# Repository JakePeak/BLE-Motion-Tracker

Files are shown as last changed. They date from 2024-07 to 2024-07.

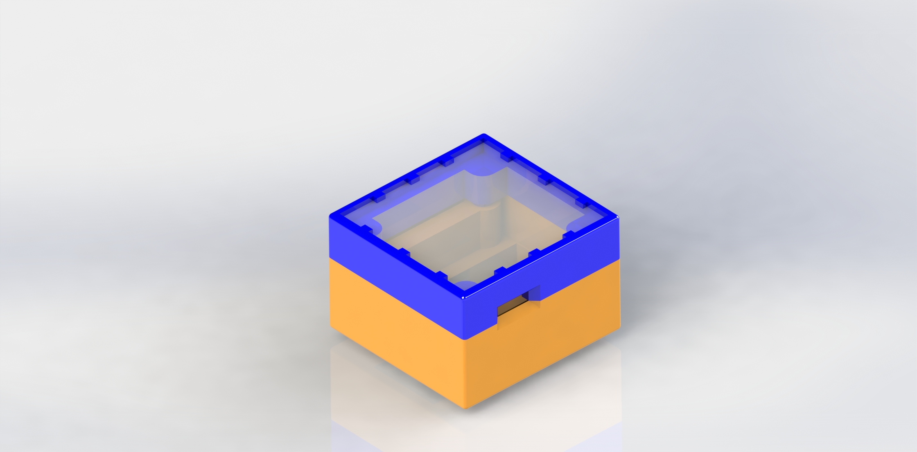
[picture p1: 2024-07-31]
PCB/Mounting/Rendered.JPG

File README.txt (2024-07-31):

BLE Motion Tracker
==========================================

This is a 200+ hour personal project with the purpose of plotting a live
graph of the current location of the motion tracker.  This was accomplished
through Bluetooth LE communications, Inertial Measurement Unit position
approximations, and python's matplotlib plotting capabilities.

This is truly a full-stack project; it scales all levels of design from custom
PCB design and manufacturing to developing a full user interface.  Almost all
code was written in C/C++, with a little python.  At the heart of this
project's functionality lies the BlueNRG M2SA module, which was used to
opperate the PCB and run all bluetooth communications with the host computer.

Throughout this project, I have picked up many skills.  These are all 
documented with their respect parts of the project, located throughout this 
repository.  As well, some of the most time-consuming bugs and errors I 
encountered are documented for any who stumble upon this project when searching
for solutions to these bugs like I have.

For more information on each individual sub-component of this project, look
for the respective README files in that location of the repository.

If you have any questions, I would love to answer them.  Attached is my 
LinkedIn profile, so you can get in touch.
www.linkedin.com/in/jake-ashpole-3b73542a7

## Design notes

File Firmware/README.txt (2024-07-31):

On-Chip Firmware
=======================================

One of the main reasons behind this project was an opportunity to teach myself
embedded software/firmware and flashing.  Thoughout this project, I will refer
to any embedded software as firmware, as firmware is a loosely defined concept.
In this directory, there are 4 folders.  Debug_LED contains a WISE Studio
project that was used to unit test and debug on-board functions and peripherals.
The rest were used as modifications to the BLE_SensorDemo demo project provided
by the WISE Studio software development kit.  This README will contain 5
sections: design overview, running the project in the IDE, skills involved, 
bugs, and references.

Design Overview
---------------------------------------

The initial concept behind the design is a 3-state state machine.  After an
on-boot initialization process, the device would enter a "connect" state, 
where it would try and develop a connection.  Once a connection is found, it
enters a "pause" state.  From the pause state, the user can activate the device,
moving into the "active" state where all peripherals are running and data is 
being send over bluetooth low energy to the external application.  The user
can toggle between pause and active states, and should the user disconnect the
device will reenter the "connect" state.

On a peripheral level, the microcontroller interacts with an LED using GPIO,
and a accelerometer using SPI.  Data is collected every select interval using
a timer through individually reading each data register.  As well, the 
microcontroller contains a build-in ADC bridge to measure the input voltage,
which is used alongside a model of output voltage decay in AAA Alkaline 
batteries to determine the battery percentage.

This device contains 6 GATT Services.  The first two are GATT and GAP services
for establishing connection.  The next 3 are the battery service, HID service, 
and device information service.  The battery service was used to hold the
battery level characteristic.  However, the HID service and device information
services are both skeleton services with little functionality, as windows has
poor support for BLE devices, which will be discussed in greater detail in the
bugs section.  The final service is a custom IMU service.  It contains 3 
characteristics: a boolean, used to change between active and pause states;
Sensor location and Speed, used to hold IMU data; a custom notify, which sends
a notification for the application to initiate a long read on the IMU data.

Running the Project
----------------------------------------

Inside BLE_SensorDemo/Release there are binary and hex files that can be
flashed without opening the project, should one desire.  Beyond this, running
the IDE will take some work.  First, download WISE Studio and its SDK off of
ST's website.  Then, opening the CPROJECT with wise studio contained within
this repository might work.  If it doesn't, then one must link the 
Additional_Source_Files to the project, specifically by right-clicking and
following the menu on the folder containing the main() function.  Doing this
project-wide breaks the SensorDemo_Config.h file, and with it all GATT 
functionality.  Afterwareds, copy the text of all the Aletered_Source_Files
into their respective files.  sensor.c contains all BlueNRG event callbacks.
SensroDemo_config.h contains the BLE stack memory allocation, which is very
buggy and the reason why I migrated my files from my own project to a demo
project.  SensorDemo_main.c contains the main function.  This should resolve
all errors, and allow for the code to be modified in the native IDE.

Debug_LED should just work, as it isn't a demo project since it has no 
bluetooth functionality.

Skills
----------------------------------------

- Embedded Firmware Design
	The core of this project was learning how to design firmware for
	microcontrollers.  I learned about numerous peripherals, register
	access, compiling, config, and flashing.  WISE studio is much more
	hands-on than the classic STM32CubeIDE, and on multiple dead end
	paths I ended up using it as well, so can confidently say that I
	am experienced in both IDEs, and with a greater understanding than most
	who simply use STM32CubeIDE for ST's products.

- Bluetooth Low-Energy Stack
	Bluetooth LE is a complex topic involving many standards and rules
	to follow.  Regardless of the microcontroller chosen, I am confident
	in my ability to design for BLE and execute.

- Flashing
	In this project, I used the built in UART flasher simply becuase it
	was cheaper than investing in a JTAG or other standard flasher.  
	However, after learning one method I am confident in my ability to 
	learn another, and have added microcontroller flashing to my skillset

- C Programming
	Wihle I already consider myself a skilled C programmer, practice makes
	perfect and writing/debugging a couple thousand lines of code on the 
	chip alone once again stands as a testament to my abilities.

- HID protocol
	Building the skeleton HID strucutre required me to learn the 
	foundations of HID, allowing me to make other devices HID-compliant

Bugs
----------------------------------------

1) WISE studio's BlueNRG_Stack_Initialization();
	The majority of this project was designed in a custom project rather
	than a demo project.  This was a much cleaner solution, but it ran
	into an issue.  The BlueNRG_Stack_Initialization function would always
	return an error.  I was unable to trace the root of this error beyond
	the User_config.h file, and like every other person I could find online,
	resorted to modifying a built-in demo application.  There is something
	innately wrong with WISE studio's custom projects, and I would like
	to document this as a warning for others using BlueNRG modules.

2) HOGP profile
	I have already discussed this under the windows_application readme,
	but there is more to it.  I was unable to translate all parts of this
	project into a HID device, as windows BLE doesn't perform a long read
	of the HID Report map.  As I couldn't alter the MTU due to limitations,
	my only option was a skeleton HOGP.  I believe this to be a bad 
	implementation, but I could see no way around it other than custom
	driver development

3) Burning IMU QFN package
	This project involved an accelerometer with a small footprint and a
	QFN package, which caused many setbacks.  As a hobbyist, my only option
	was to solder paste and heat gun.  This resulted in me burning 3/4 of
	my IMUs, to various degrees.  I would recommend avoiding QFN packages
	when possible, and if not like my situation, find and use a soldering
	specific heat gun with controllable temperatures.  Be it disfunctional
	SPI, broken pads, or busted MEMs devices damaged chips provided a host
	of issues.  While estimating position from IMU readins is already a 
	rather flawed system, damaged IMUs made my final project much less
	impressive, as the live location graphing was usually inaccurate.

4) Accelerometer SPI FIFO
	While polling individual registers works, it is much more elegant to
	read all registers at once through the accelerometer-provided FIFO.
	However, after a long time debugging this approach was abandoned.
	My accelerometer didn't like gaps between SPI data frames, and 
	my microcontroller supported a max data frame size of 32 bits, so
	I was sadly unable to get a reading out of the FIFO.  I left the
	FIFO config instructions in the final project, despite being unable
	to utilize them.

References
----------------------------------------

The microcontroller used, the BlueNRG-M2SA module, was very convenient in that
it could be hand-soldered.  While it had many bluetooth issues and limitations,
I would recommend it for hobbyists simply for the manufacturability.  From this
link, one can find the RF flasher utility, WISE studio, and the SDK.
https://www.st.com/en/wireless-connectivity/bluenrg-m2.html#documentation

The accelerometer has a host of useful functions, called APEX motion functions.
As well, the non-burnt gyroscope axis managed to be accurate to around 1/1000 
of a radian per second, so I do believe it to be a very powerful device.  Just
be cautious with temperature.
https://product.tdk.com/system/files/dam/doc/product/sensor/mortion-inertial/imu/data_sheet/ds-000451-icm-42670-p.pdf

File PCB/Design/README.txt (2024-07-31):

PCB Design
=================================

This folder contains the two iterations of my PCB design.  The first was never
ordered, but played a crucial role in the design process.  When designing, I
chose to use Altium, as I have used it though Illini Electric Motorsports.

Verson 1
---------------------------------

The first version of the PCB was much smaller.  It assumed components would
be mounted externally, and would be wired and soldered into vias.  As well,
I designed it before I knew the feasibility of soldering QFN packages for the
accelerometer, so left vias to manually wire into the accelerometer.  I decided
this was a poor solution, hence the redesign.  As well, the PCB manufacturer
I used had limited support for small boards, and my board was too small.  This
led me to redesign the board and make it larger, leaving space for more 
mounting holes.

Version 2
---------------------------------

The final version of the PCB.  It features additional mounting holes to 
directly mount the battery pack to the PCB, which while not a very resilient
solution was very convenient for keeping all electronic components together
during software/firmware development.  The PCB features a flashing switch, as
well as an on/off switch.  It has a USB-UART connector for utilizing the
microcontrollers UART bootloader.  It also uses an LED/resistor output, to
help debug and calculated to have low power consumption.  As well, SPI lines
are routed from the PCB to the accelerometer.  All other resistors are pull-up
resistors, and all capacitors are bypass capacitors.  J2 was originally a
connector, however it's footprint was wrong so wires were directly soldered to
the VIAs.  The board also utilizes two power planes (ground and 3V), making
it a 4 layer board.

Skills
---------------------------------

- Digital Circuit Design
	While simple, this project gave me an introduction to digital circuit
	design.  All my digital traces worked perfectly as intended.

- PCB design
	Outside of mounting holes, this is a relatively robust PCB.  I am more
	than capable of making it significantly smaller, but took advantage
	of the extra space requirements to improve manufacturability.

- Analog Circuit Design
	This feature did feature one analog component, the LED.  While simple,
	it was consistent and error-free

- Soldering
	Not only did I get to use classic soldering using an iron, I also got
	exposure to heat gun soldering and solder paste.  While I lost many
	accelerometers to this process, I am confident in my ability to 
	manufacture QFN packages in the future with use of reflow diagrams.
	I am a longtime solderer, and this was just another opportunity to
	work with it.

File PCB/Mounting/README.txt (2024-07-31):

PCB Mounting
===================================

This file contains the SolidWorks CAD documents used to produce the casing
for the PCB.  This was a rather simple construction, with attention to detail
to reduce the need for supports for 3d prints and make resource-efficient 
joining methods between different parts.  As well, a laser cutter was
used to cut out a plexiglass cap for the mount to leave the circuit on
display, since it was the heart of the project.  A final render is included
in this folder, as well as documents for laser cutting.

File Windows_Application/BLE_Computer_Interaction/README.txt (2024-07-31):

Overview of the Windows Application
=========================================

This directory contains the visual studio 2022 project in which the laptop
application which interacts with the motion tracker resides.  This document
consists of 5 segments: how to run the project in visual studio, how to
use the project, skills involved, largest bugs, and references.

How to Run in Visual Studio
-----------------------------------------
While the project should work fine on its own, any attempt to compile will
inevitably fail.  This project is dependent on two external libraries, the
C-python API and Eigen.  When I constructed this, I manually installed them
into the Visual Studio default library location, which would let me use them
on further projects.  If you would rather not, I recommend downloading both
libraries and altering the framework.h header file with the necessary paths
and .dlls.  Since this isn't designed to be a public utility, but rather a
skills showcase, hard-coding my personal setup made the most sense rather
than reuploading those APIs to Github.

Using the Project
-----------------------------------------
To start this project, double click or run the compiled executable from the
command line.  It should prompt you to select your python application.  While
I originally empedded python into the project, the embedded distribution 
has compatibility issues with importing libraries using the C-Python APIs, so
rather than embedded a full python download I opted to use the user's python.

After this, the application window should open.  It is rather simple, as 
this project focuses on the lower levels of the full-stack implementation.
The menu is rather reduntant, however the python tab is useful for configuring
the embedded python.  As for the buttons:
- Connect     --> connects the application to the device
- Pause       --> Pause the devices data collection (enters pause state)
- Unpause     --> Starts data collection (enters active state)
- Battery     --> Outputs current battery percentage
- Import File --> Select an external file to graph, ie. prior saved data
- Set Output  --> Allows for changing from the default output CSV
- Disconnect  --> Disconnects the application from the device

If the device has already been connected to the PC by finding it under the
extended connectable bluetooth devices list, then connect should complete
without error.  Then simply select unpause to start graphing.  The device
first will calibrate, which is signaled by the LED turning on until
calibration is complete.  Then data will be plotted live, until the window
is exited or the pause button is selected.

Skills Involved
-----------------------------------------
In creating this application, I primarily learned about different API sets,
as well as the windows system.

1) C++ coding with Object Oriented Programming (OOP)
	The way python interaction and bluetooth device interaction was coded
	closely followed the principles of OOP, and helped developed my
	programming skills.

2) win32 API set
	I used a large swath of the win32 api.  The most notable were the 
	BLE device node APIs, the device enumeration APIs, and the windowing
	APIs.  To help understand these and get my device to connect to them,
	I also researched the win32 device driver stack, although due to time
	constraints and the steep learning curve I left it for a later projet.
	Out of these API sets, the device enumeration APIs are the most
	generally useful, as I see myself working with other forms of device
	I/O in the future.

3) C-Python APIs
	After using these APIs, I strongly discourage their use.  They 
	natively introduced a host of bugs and compatibility issues, 
	especially with library imports.  However, I do find it very 
	appealing to be able to call python code from C, and could see myself
	utilizing them in the future, now that I know many of the issues to
	avoid when using them.

4) Eigen
	I used a little bit of Eigen and linear algebra to estimate position
	using the Inertial Measurement Unit.  The mathematics was interesting,
	and I found Eigen to be a very consistent solution to my problems.

5) Multithreading
	While I have already covered multithreading in advanced coursework,
	I opted to somewhat utilize it in this project.  The two locations
	where I used it was operating an independent 'python' thread and
	using asynchronous file IO to streamline data throughput over BLE.

6) Full-Stack Development
	The massive scope of this project as a whole provided an introduction
	to full-stack development unlike one any normal project could deliver.

Bugs
-----------------------------------------
As I have covered the numerous python bugs in that respective README, I will
not review them here.

- LEEnumerator driver
	The windows-provided basic BLE driver has numerous pitfalls, and almost
	pushed me to design my own.  If it doesn't detect a GATT profile
	device, then it will disconnect the device and won't permit 
	connections.  While not an elegent solution, I found the only way shy
	of designing my own driver was to build a mock HID Over Gatt Profile
	(HOGP) profile on my device.  While I followed all regulations and
	standards, I very much dislike the need for this solution simply 
	because the LEEnumerator driver doesn't need to have this arbitrary
	requirement, custom services work just fine if it detects any GATT
	profile.

- Dots Per Inch (DPI) nonfunctional with MatPlotLib
	When attempting to use the visual studio example code as the foundation
	of my windowing, I ran into an issue where after making MatPlotLib 
	calls my window would randomly resize.  I was able to track this issue
	down to an application error where it didn't inately use the system's
	DPI.  I suspect this issue could happen for many other reasons, and
	the solution was to add:
	SetThreadDpiAwarenessContext(DPI_AWARENESS_CONTEXT_SYSTEM_AWARE)
	as the application initialized.

- Bluetoothleapis.h poor documentation
	While not a bug, the documentation deserves it's own discussion.  As
	the only non-UWP microsoft API set to interact with BLE devices, it
	should have better documentation.  Notably, the documentation often
	confuses device handles with service handles.  If running into bugs
	with this API set, check which seems more intuitive first, as the 
	documentation sometimes directly contradicts itself as to which is 
	correct.

As with any project, bugs are commonplace, however these were some of the most
prominent bugs encountered.  That being said, I found Visual Studio 2022 to be
a very bug-free IDE which helped me solve my problems quickly and efficiently.

References
-----------------------------------------

The win32 documentation is very extensive, and for the most part, very good.
Below is the link to their error documentation, as sometimes the application
reports win32's error codes.
https://learn.microsoft.com/en-us/windows/win32/debug/system-error-codes--0-499-

To help learn how use the windowing APIs, I found "The PentaMollis Project"'s 
youtube series to be a lifesaver to quickly introduce the important features
of this vast API set.
https://www.youtube.com/playlist?list=PLWzp0Bbyy_3i750dsUj7yq4JrPOIUR_NK

The C-Python API reference manual, while not as thorough as it could be, was
essential for debugging, and is linked below.
https://docs.python.org/3/c-api/index.html

Bluetooth SIG does a great job documenting all of the defined profiles, and
allowed me to implement my ghost HOGP profile to get around LEEnumerator's 
defficiencies.
https://www.bluetooth.com/specifications/specs/

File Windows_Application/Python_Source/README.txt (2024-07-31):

Python Embedding Information
============================

Getting it Operational
----------------------------

In the windows application, I chose to embbed python using the c-python api,
which ultimately had many issues.  While most of this will work out of the
box, there are a couple steps that must be done.

1) Edit the path to <Python.h> to your own respective python.h
	- Make sure to have Numpy and Pandas installed

2) Edit the path to <Eigen\Dense> to your own eigen install
	- This is a rather easy library to download, so I didn't include
	  it in the final project

Notable Pitfalls and Bugs
----------------------------

Throughout the development of this project, the python embedded installation
took much longer than was anticipated due to a combination of external modules
and a nontrivial API.  Should anyone attempt to build their own embedded python
installation using this API, here are some recommentations.

1) External Modules (Numpy, MatplotLib) aren't designed to work well with this
API set.  These two modules gave me countless troubles, and here were my
solutions.
	- Numpy can only be initialized once
		- If you want to embed Numpy, Don't repeatedly Py_FinalizeEx()
		  and Py_Initialize().  As part of its startup, it only works
		  the first time.

	- Matplotlib rescales the application's DPI and steals focus
		- At least with win32, calling on Matplotlib is very dangerous.
		  SetThreadDpiAwarenessContext(DPI_AWARENESS_CONTEXT_SYSTEM_AWARE);
		  is was required, as it would rescale windows if they didn't
		  adapt to the system DPI that matplotlib would overlap
		- As well, if building your own animation method, use rcParams.
		  Specifically, "figure.raise_window" = False.  Without this,
		  every time the plot resets it steals focus, stoping the
		  user from accessing the rest of the application.

2) In my experience, I was unable to get the embedded windows distribution of
Python to work.  I believe this is because the API doesn't look for standard
modules in .pyc files, so it cannot import any modules.  Outside of the simplest
implementations, it is required to have a full version of python "embedded"
into the software, which can be a large space constraint, hence why it wasn't
used.

3) Reference counts are powerful and if used incorrectly, the source of many
bugs.  I strongly recommend anyone familiarize themselves with that 
documentation.

Content Overview
----------------------------

The heart of the python distribution lies in MakeGraph.py.  Small but mighty,
it has code for everything necessary.  Debug.py was a simple debug script
used for debugging, as well as PythonSetup.py.  libs and DLLs are self 
explanitory.  Finally, data3D.csv is an example dataset that can be run from
the application individually for testing without building the actual device.

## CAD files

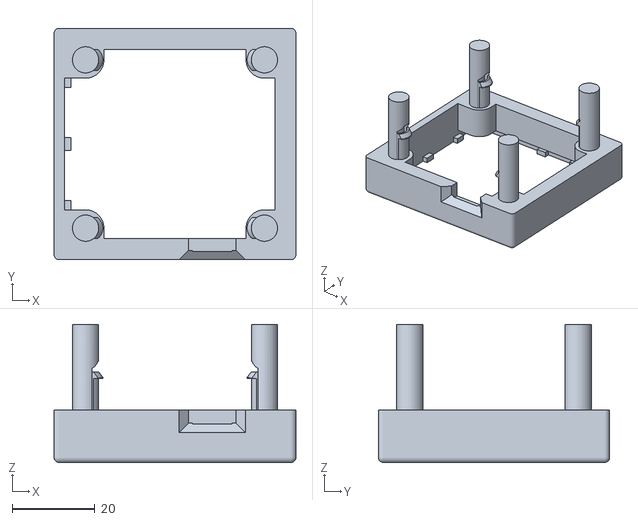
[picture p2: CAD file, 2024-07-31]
PCB/Mounting/Overhead_Mount_Full.STL
58.4 x 55.9 x 33.3

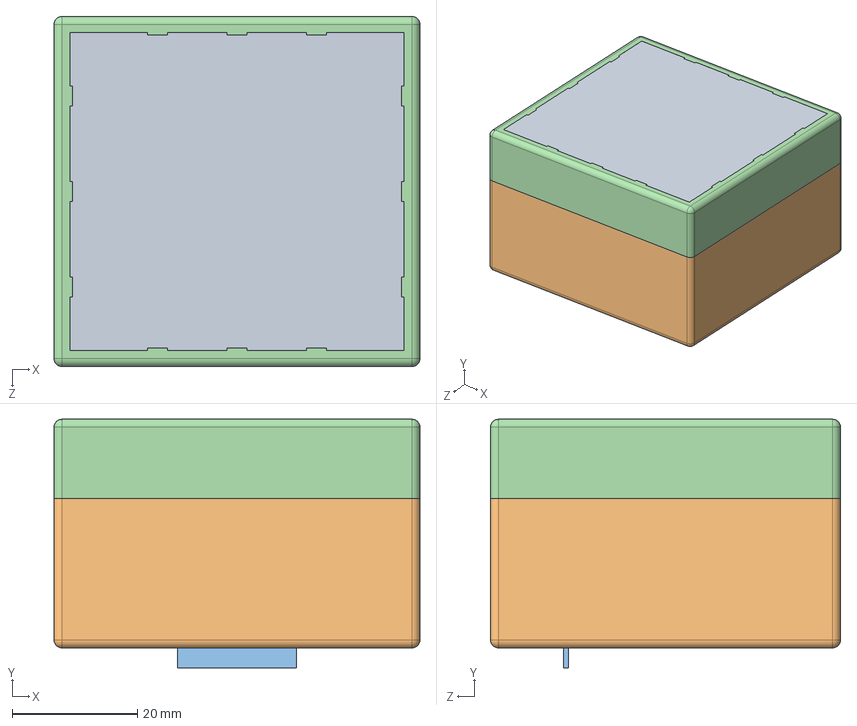
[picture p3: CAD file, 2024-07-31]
PCB/Mounting/Full_Assembly.SLDASM
58.4 x 39.7 x 55.9 mm
Overhead_Mount
Battery_Cover
Underside_Mount
Plexiglass_Cover

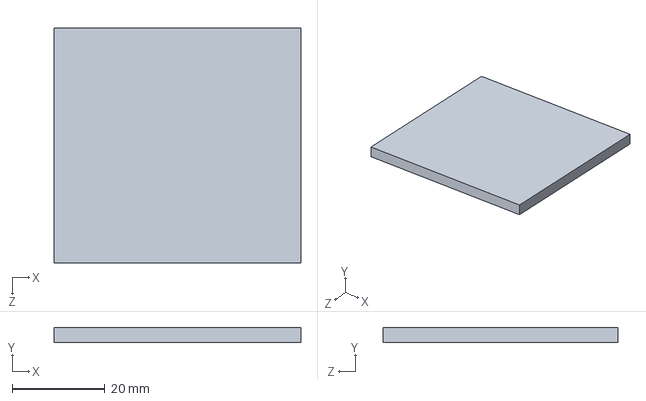
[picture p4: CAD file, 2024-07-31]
PCB/Mounting/Plexiglass_Cover.SLDPRT
53.3 x 3.17 x 50.8 mm

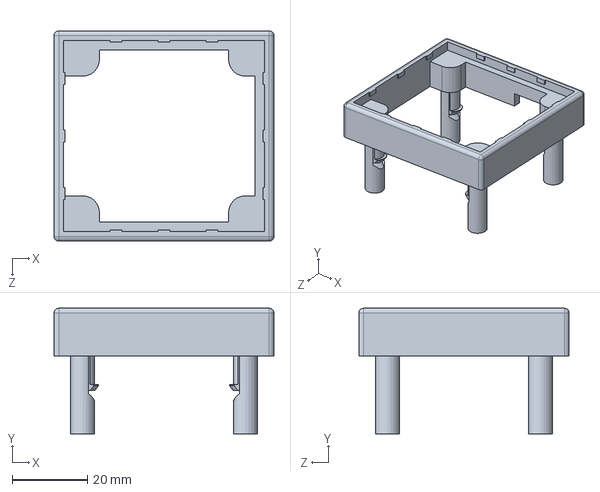
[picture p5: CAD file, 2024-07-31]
PCB/Mounting/Overhead_Mount.SLDPRT
58.4 x 33.3 x 55.9 mm

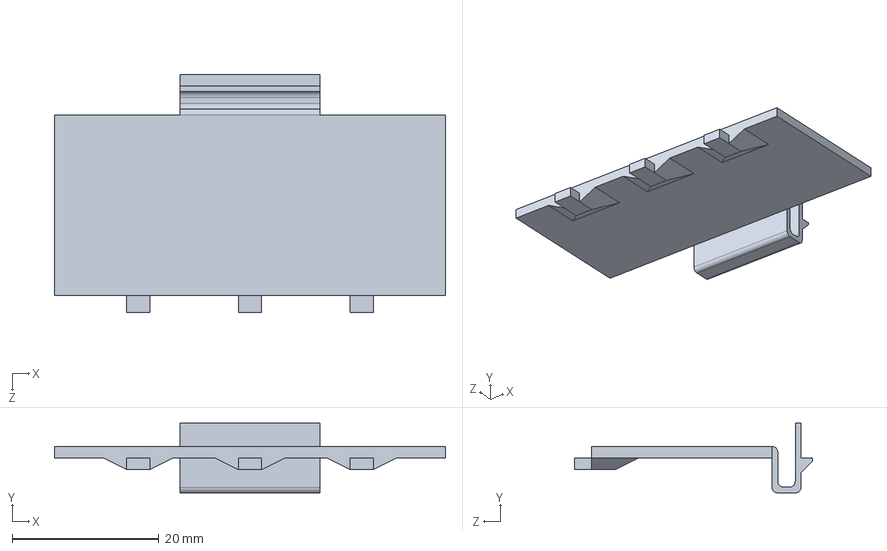
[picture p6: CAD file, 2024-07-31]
PCB/Mounting/Battery_Cover.SLDPRT
53.3 x 9.53 x 32.5 mm

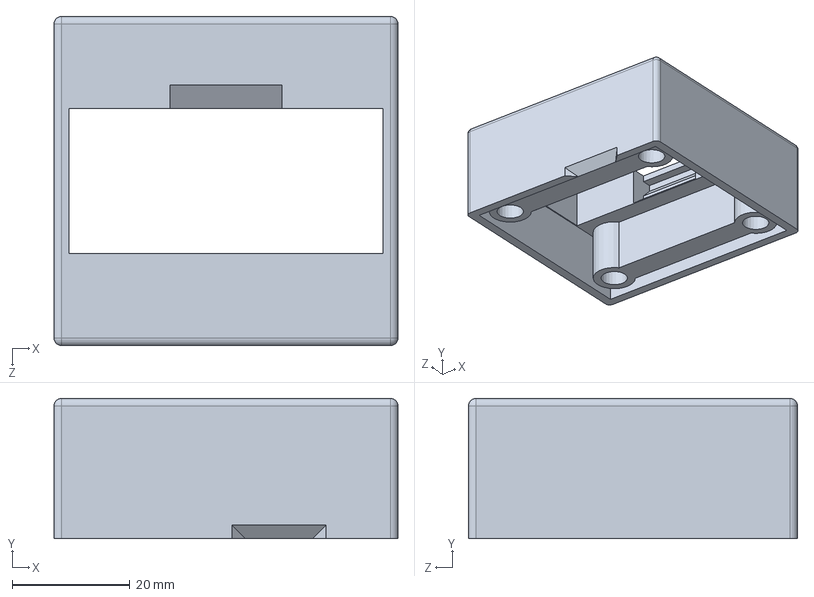
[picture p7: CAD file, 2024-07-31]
PCB/Mounting/Underside_Mount.SLDPRT
58.4 x 23.8 x 55.9 mm

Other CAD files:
PCB/Mounting/Plexiglass_Laser_Drawing.SLDDRW

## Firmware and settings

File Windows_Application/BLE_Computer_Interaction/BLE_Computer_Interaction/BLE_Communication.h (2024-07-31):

#pragma once
// Mark as included
#include "framework.h"

// Bluetooth GATT/GAP information
#define DEVICE_NAME {L'M', L'o', L't', L'i', L'o', L'n', L' ', L'T', L'r', L'a', L'c', L'k', L'e', L'r', L'\0'}
#define DEVICE_ADDRESS { (char)0xC2,(char)0xBC,(char)0x36,(char)0xAD,(char)0x26,(char)0xC5,(char)0x00 }
#define ACCEL_UUID GUID {0xD03AC8B6, 0x59E9, 0x4E59, {0x84, 0x6A, 0x32, 0xAA, 0x3C, 0xB7, 0x12, 0xBC} }
#define BATTERY_SERVICE_UUID (USHORT)0x180F
#define HID_UUID (USHORT)0x1812
#define BATTERY_UUID (USHORT)0x2A19
#define DATA_UUID (USHORT)0x2A67
#define PAUSE_STATE_UUID (USHORT)0x2AE2
#define READY_UUID GUID {0xD03AC8B9, 0x59E9, 0x4E59, {0x84, 0x6A, 0x32, 0xAA, 0x3C, 0xB7, 0x12, 0xBC} }
//#define REPORT_UUID (USHORT)0x2A4D
#define CCC_UUID (USHORT)0x2902
#define ACCEL_UUID_STRING_LEN 36

// Time it takes for device to have a successful callibration, in seconds
#define CALLIBRATION_TIME 15
// Tolerance of callibration
#define TOLERANCE .05
// Default output CSV name
#define DEFAULT_NAME "BLE_output_file"
#define DEFAULT_NAME_WIDE L"BLE_output_file"
#define EXECUTABLE_NAME L"BLE_Computer_Interaction.exe"
// Optional caps for graphing data to keep accelerometer data reasonable
#define VELOCITY_CAP 10
#define POSITION_CAP 50

// Data Parsing Macros
#define POINTS_PER_PACKET 10
#define SAMPLE_RATE .025
#define CALLIBRATION_PACKETS  ((CALLIBRATION_TIME/SAMPLE_RATE)/POINTS_PER_PACKET)
#define MAX_INT (double)32768
#define GYRO_SCALE (double)2000
#define ACCEL_SCALE (double)16
#define GS_TO_MPS2 (double)9.80665
#define CALLIBRATION_COMPLETE (0x02)


typedef enum _PAUSE_STATE {PAUSE, UNPAUSE} PAUSE_STATE;
typedef enum _FILE_MODE {NONE, PATH, NAME} FILE_MODE;

/*
 * @brief	Struct containing information to be given as context to the callback function.  It
 *			provides information on the previous point, as well as if the last packet was read.
 */
typedef struct {
	bool Callibrated;
	int CallibrationCounter;
	double x;
	double y;
	double z;
	double Vx;
	double Vy;
	double Vz;
	int16_t anglexComp;
	int16_t angleyComp;
	int16_t anglezComp;
	double anglex;
	double angley;
	double anglez;
	double scale;
	USHORT AttributeHandle;
	HANDLE* ServPtr;
	PBTH_LE_GATT_CHARACTERISTIC DataPtr;
	PBTH_LE_GATT_CHARACTERISTIC NotifPtr;
	HANDLE fileHandle;
}BLE_CALLBACK_CONTEXT;

/* 
 * @brief	Primary BLE device class, representing an individual BLE device.  Methods are sepecified
 *			in BLE_Communication.cpp, as well as their documentation and error codes
 */
class BLE_Device{
private:
	HANDLE DevHandle;
	HANDLE ServHandle;
	HANDLE BattServHandle;
	BTH_LE_GATT_SERVICE IMU;
	BTH_LE_GATT_SERVICE BatteryService;
	BTH_LE_GATT_CHARACTERISTIC Battery;
	BTH_LE_GATT_CHARACTERISTIC Data;
	BTH_LE_GATT_CHARACTERISTIC Pause;
	BTH_LE_GATT_CHARACTERISTIC Ready;
	BTH_LE_GATT_DESCRIPTOR CCC;
	BLUETOOTH_GATT_EVENT_HANDLE NotifyHandle;
	BLUETOOTH_GATT_VALUE_CHANGED_EVENT_REGISTRATION* NotifyHandleRegistration;
	BLE_CALLBACK_CONTEXT* CallbackContext;
	std::string* FilePath;

	static void ParseAccelData(int16_t* x, int16_t* y, int16_t* z, UCHAR* data, int offset);
	static int GetExecPath(WCHAR** out);
public:
	int ErrorCode;

	// Standard Member Functions
	BLE_Device(HWND hWnd);
	~BLE_Device();
	int EnterState(PAUSE_STATE State);
	void ClearCSV();
	uint8_t BatteryPercentage();

	// Setter/getter functions
	void SetFilePath(std::string& input, FILE_MODE mode);
	const std::string* GetFilePath() { return FilePath; }		// Outputs current filepath

	// Function callbacks
	static void ReadNotifcationData(BTH_LE_GATT_EVENT_TYPE EventType, PVOID EventOutParameter, PVOID Context);
	static void FileIOCallback(DWORD dwErrorCode, DWORD dwNumberOfBytesTransfered, LPOVERLAPPED lpOverlapped);

	// copy, default, and copy assignment methods removed
	BLE_Device() = delete;
	BLE_Device(BLE_Device const &device2) = delete;
	void operator=(BLE_Device const &device2) = delete;
};

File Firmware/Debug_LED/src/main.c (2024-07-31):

/*
 * main.c
 *
 *  Created on: Jul 3, 2024
 *      Author: akj56
 */
#include "main.h"

uint8_t packet_counter;
uint8_t packet_data[60];

int main(void){
	SystemInit();
	SdkEvalIdentification();
	SdkEvalComUartInit(UART_BAUDRATE);
	Clock_Init();
	SPI_User_Init();
	ADC_User_Init();
	Accel_Init();
	packet_counter = 0;
	uint8_t debugState = 0x00, counter = 0;
	uint32_t buf = 1;

	Error(0);

	Enable_Accel(ENABLE);

	while(1){
		switch(debugState){
		case(0x00):
				// Debug 1, Check LED
			GPIO_SetBits(ERROR_LED);
			Clock_Wait(1000);
			GPIO_ResetBits(ERROR_LED);
			Clock_Wait(1000);
			nextState(&debugState);
			break;
		case(0x01):
				// Debug 2, Check SPI
			buf = 0x00;
			SPI_Write(PWR_MGMT0_ADDR, 0x1F);
			SPI_Read(MCLK_RDY_ADDR, &buf);
			if(buf == 9){
				Error(1);
			}
			if(buf != 9){
				Error(3);
			}
			//SPI_Write(PWR_MGMT0_ADDR, 0x00);
			Clock_Wait(100);
			nextState(&debugState);
			break;
		case(0x02):
				// Debug 3, Check ADC
			buf = (uint8_t)ADC_RequestBattery();
			if(buf >= 1){
				Error(0);
			}
			else{
				Error(1);
			}
			buf = 0;
			Clock_Wait(1000);
			GPIO_SetBits(ERROR_LED);
			Clock_Wait(1000);
			GPIO_ResetBits(ERROR_LED);
			nextState(&debugState);
			Clock_Wait(1000);
			break;
		case(0x03):
					// Debug 4, Check SPI Output
			GPIO_ResetBits(SPI_CS);
			//SPI_SetNumFramesToTransmit(4);
			//SPI_SetNumFramesToReceive(4);
			SPI_Cmd(DISABLE);
			SPI_Cmd(ENABLE);
			SPI_SendData(0xA0C0A0C1);
			GPIO_SetBits(ERROR_LED);
			Clock_Wait(500);
			GPIO_SetBits(SPI_CS);
			GPIO_ResetBits(ERROR_LED);
			Clock_Wait(500);
			nextState(&debugState);
			break;
		case (0x04):
					// Debug 5, read accel data function
			GPIO_ResetBits(SPI_CS);
			Request_Accel_Data();
			GPIO_SetBits(SPI_CS);
			Clock_Wait(500);
			nextState(&debugState);
			break;
		default:
			// Loop back to beggining on default
			debugState = 0x00;
			break;
		}
	}
	return 0;
}
/*
 * @brief 	Checks to advance to next state
 * @param	State to advance
 */
void nextState(uint8_t* debugState){
	if(GPIO_ReadBit(TOGGLE_SWITCH) == Bit_SET){
		// Make sure actually set
		Clock_Wait(100);
		if(GPIO_ReadBit(TOGGLE_SWITCH) == Bit_SET){
			(*debugState)++;

			while(GPIO_ReadBit(TOGGLE_SWITCH == Bit_SET)){
				// Wait to undo switch
				GPIO_SetBits(ERROR_LED);
				Clock_Wait(100);
				if(GPIO_ReadBit(TOGGLE_SWITCH != Bit_SET)){
					break;
				}
				GPIO_ResetBits(ERROR_LED);
				Clock_Wait(100);
			}

		}
	}
}

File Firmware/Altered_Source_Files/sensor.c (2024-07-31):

/******************** (C) COPYRIGHT 2015 STMicroelectronics ********************
 * File Name          : sensor.c
 * Author             : AMS - VMA RF Application team
 * Version            : V1.0.0
 * Date               : 23-November-2015
 * Description        : Sensor init and sensor state machines
 ********************************************************************************
 * THE PRESENT FIRMWARE WHICH IS FOR GUIDANCE ONLY AIMS AT PROVIDING CUSTOMERS
 * WITH CODING INFORMATION REGARDING THEIR PRODUCTS IN ORDER FOR THEM TO SAVE TIME.
 * AS A RESULT, STMICROELECTRONICS SHALL NOT BE HELD LIABLE FOR ANY DIRECT,
 * INDIRECT OR CONSEQUENTIAL DAMAGES WITH RESPECT TO ANY CLAIMS ARISING FROM THE
 * CONTENT OF SUCH FIRMWARE AND/OR THE USE MADE BY CUSTOMERS OF THE CODING
 * INFORMATION CONTAINED HEREIN IN CONNECTION WITH THEIR PRODUCTS.
 *******************************************************************************/
/* Includes ------------------------------------------------------------------*/
#include <stdio.h>
#include <string.h>
#include "BlueNRG1_it.h"
#include "BlueNRG1_conf.h"
#include "ble_const.h" 
#include "bluenrg1_stack.h"
#include "gp_timer.h"
#include "SDK_EVAL_Config.h"
#include "gatt_db.h"
#include "BLE_User_main.h"
#include "bluenrg1_api.h"
#ifndef SENSOR_EMULATION
#include "LPS25HB.h"
#include "lsm6ds3.h"
#include "LSM6DS3_hal.h"
#endif
#include "OTA_btl.h"   
/* Private typedef -----------------------------------------------------------*/
/* Private define ------------------------------------------------------------*/
#ifndef DEBUG
#define DEBUG 0
#endif

#if DEBUG
#include <stdio.h>
#define PRINTF(...) printf(__VA_ARGS__)
#else
#define PRINTF(...)
#endif

#define UPDATE_CONN_PARAM 0 
#define  ADV_INTERVAL_MIN_MS  500
#define  ADV_INTERVAL_MAX_MS  600

#define BLE_SENSOR_VERSION_STRING "1.1.0" 

/* Private macro -------------------------------------------------------------*/
/* Private variables ---------------------------------------------------------*/
volatile uint8_t set_connectable = 1;
uint16_t connection_handle = 0;
uint8_t connInfo[20];

BOOL sensor_board = FALSE; // It is True if sensor boad has been detected

int connected = FALSE;
#if UPDATE_CONN_PARAM
#define UPDATE_TIMER 2 //TBR
int l2cap_request_sent = FALSE;
static uint8_t l2cap_req_timer_expired = FALSE; 
#endif

#define SENSOR_TIMER 1
static uint16_t acceleration_update_rate = 200;
static uint8_t sensorTimer_expired = FALSE;

#ifndef SENSOR_EMULATION
PRESSURE_DrvTypeDef* xLPS25HBDrv = &LPS25HBDrv;  
IMU_6AXES_DrvTypeDef *Imu6AxesDrv = NULL;
LSM6DS3_DrvExtTypeDef *Imu6AxesDrvExt = NULL;
static AxesRaw_t acceleration_data; 
#endif 

volatile uint8_t request_free_fall_notify = FALSE; 
  
/* Private function prototypes -----------------------------------------------*/
/* Private functions ---------------------------------------------------------*/

#ifndef SENSOR_EMULATION

static IMU_6AXES_InitTypeDef Acc_InitStructure; 
/*******************************************************************************
 * Function Name  : Init_Accelerometer.
 * Description    : Init LIS331DLH accelerometer.
 * Input          : None.
 * Output         : None.
 * Return         : None.
 *******************************************************************************/
void Init_Accelerometer(void)
{
  /* LSM6DS3 library setting */
  uint8_t tmp1 = 0x00;
  
  Imu6AxesDrv = &LSM6DS3Drv;
  Imu6AxesDrvExt = &LSM6DS3Drv_ext_internal;
  Acc_InitStructure.G_FullScale      = 125.0f;
  Acc_InitStructure.G_OutputDataRate = 13.0f;
  Acc_InitStructure.G_X_Axis         = 0; //1;
  Acc_InitStructure.G_Y_Axis         = 0;//1;
  Acc_InitStructure.G_Z_Axis         = 0; //1;
  Acc_InitStructure.X_FullScale      = 2.0f;
  Acc_InitStructure.X_OutputDataRate = 13.0f;
  Acc_InitStructure.X_X_Axis         = 1;
  Acc_InitStructure.X_Y_Axis         = 1;
  Acc_InitStructure.X_Z_Axis         = 1;  
  
  /* LSM6DS3 initiliazation */
  Imu6AxesDrv->Init(&Acc_InitStructure);
    
  /* Disable all mems IRQs in order to enable free fall detection */ //TBR
  LSM6DS3_IO_Write(&tmp1, LSM6DS3_XG_MEMS_ADDRESS, LSM6DS3_XG_INT1_CTRL, 1);
  
  /* Clear first previous data */
  Imu6AxesDrv->Get_X_Axes((int32_t *)&acceleration_data);
  
  /* Enable Free fall detection */
  Imu6AxesDrvExt->Enable_Free_Fall_Detection(); 
}

static PRESSURE_InitTypeDef Pressure_InitStructure;

/*******************************************************************************
 * Function Name  : Init_Pressure_Temperature_Sensor.
 * Description    : Init LPS25HB pressure and temperature sensor.
 * Input          : None.
 * Output         : None.
 * Return         : None.
 *******************************************************************************/
void Init_Pressure_Temperature_Sensor(void)
{  
  /* LPS25HB initialization */

  Pressure_InitStructure.OutputDataRate = LPS25HB_ODR_1Hz;
  Pressure_InitStructure.BlockDataUpdate = LPS25HB_BDU_READ; //LPS25HB_BDU_READ LPS25HB_BDU_CONT
  Pressure_InitStructure.DiffEnable = LPS25HB_DIFF_ENABLE;  // LPS25HB_DIFF_ENABLE
  Pressure_InitStructure.SPIMode = LPS25HB_SPI_SIM_3W;  // LPS25HB_SPI_SIM_3W
  Pressure_InitStructure.PressureResolution = LPS25HB_P_RES_AVG_32;
  Pressure_InitStructure.TemperatureResolution = LPS25HB_T_RES_AVG_16;  
  xLPS25HBDrv->Init(&Pressure_InitStructure);
}

/*******************************************************************************
 * Function Name  : Init_Humidity_Sensor.
 * Description    : Init HTS221 temperature sensor.
 * Input          : None.
 * Output         : None.
 * Return         : 0 if success, 1 if error.
 *******************************************************************************/
int Init_Humidity_Sensor(void)
{
  /* No humidity sensor available on BlueNRG-1 Application Board*/
  return 0;
}
#endif
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
